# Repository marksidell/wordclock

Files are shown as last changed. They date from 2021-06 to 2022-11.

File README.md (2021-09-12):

# Word Clock

*View a 
<a href="https://www.youtube.com/watch?v=zEZTya65sJE" target="_blank">
video tour</a> of the word clock at YouTube.*

*Read all about the project on the
<a href="https://github.com/marksidell/wordclock/wiki" target="_blank">
wiki</a>.*

<a href="https://docs.google.com/spreadsheets/d/e/2PACX-1vQStdv3OZqONGQ3K7h9tHB2eYP5Ft4sCtjWJ84ZjRLP-8blSC_7sYkqp4zAAOey4n2pG4VfOC5HdfLr/pubhtml" target="_blank">
Bill of Materials</a>

## Repo Contents

### Directories

See the `README` file in each directory for more information.

| Directory | Description |
|---|---|
| <a href="https://github.com/marksidell/wordclock/tree/main/carbide3d" target="_blank">carbide3d</a> | Carbide Create designs for various clock components. |
| <a href="https://github.com/marksidell/wordclock/tree/main/code" target="_blank">code</a> | The code that needs to be copied to the Pi. |
| <a href="https://github.com/marksidell/wordclock/tree/main/code" target="_blank">docs</a> | The manual and other printed material. |
| <a href="https://github.com/marksidell/wordclock/tree/main/face" target="_blank">face</a> | Adobe Illustrator face designs for the clocks I've built. |
| <a href="https://github.com/marksidell/wordclock/tree/main/pcbs" target="_blank">pcbs</a> | KiCad printed circuit board designs. |

### Files

| File | Description |
|---|---|
| <a href="https://github.com/marksidell/wordclock/blob/main/aws-s3-policy-example.json" target="_blank">aws-s3-policy-example.json</a> | An example AWS IAM policy file for granting the word clock S3 permissions. |
| <a href="https://github.com/marksidell/wordclock/blob/main/manual.docx" target="_blank">manual.docx</a> | The user manual. |
| <a href="https://github.com/marksidell/wordclock/blob/main/pi-pinouts.md" target="_blank">pi-pinouts.md</a> | What passes for a schematic. |

## How It Works

### The Clock Program

The clock program, `wc`, runs as a systemd service. It must run as root to be able to
access the I2C hardware. The program uses the Python `asyncio` framework
for orchestrating real-time processes. You can also run the program from the command line,
with options to display verbose debugging messages.

### Calibrating the Compass

Each clock's magnetometer must be calibrated. The result of the calibration is stored
as a JSON file, `/var/wordclock/compass.json`. The word clock program reads the file
on startup. To perform a calibration, start the `calibrate` program and then slowly
rotate the magnetometer through all possible orientations.

### Phoning Home

The clock can be configured to phone home periodically, to upload systemd logs for
the clock service, and to download and install new software. The clock phones home
simply by reading and writing an AWS S3 bucket.

The clock uploads a log file daily, and saves it as `logs/<username>/log-<timestamp>.txt`,
where `<username>` is the IAM user name you'll create, as described below.

The clock checks for updates hourly. See the documentation in `wordclock/get_update.py`
for more information.

Here's what you'll need to do to make the phone-home feature work:

1. Create an S3 bucket.
2. Create an IAM User for your clock and grant it permission to access the bucket.
The file `aws-s3-policy-example.json` is an example IAM policy.
3. Create AWS API credentials for the user. Download the credential strings and store
them on the Pi, in the `[default]` section of file `/root/.aws/credentials`.

### Test Programs

The Python package includes several test programs:

| Program | Description
|---|---|
| tneo | Send test patterns to the neopixels. |
| tsense | Test and report values for the sensors: magnetometer, accelerometer, and light sensor. |
| calibrate | Calibrate the magnetometer. |

## Setting up the Pi

Notes to myself:

- Add my own ssh public key to `/home/pi/.ssh/authorized_keys`.

- Allow ssh agent forwarding when root by creating a sudoers file.
  This will allow me to use ssh to access github.

  ```
  visudo -f /etc/sudoers.d/ssh_agent_forwarding
  ```

  In VI add this line and save the file:

  ```
  Defaults env_keep += "SSH_AUTH_SOCK"
  ```

- Add this line to `/root/.ssh.config` so that I can ssh to other servers when root:

  ```
  User <my-username>
  ```

- Add wordclock-<xx> AWS credentials to `/root/.aws/credentials`:

  ```
  [default]
  aws_access_key_id = <key>
  aws_secret_access_key = <secret>
  ```

## Installation

1. Using `raspi-config`, enable `i2c`.

2. Get the contents of this repo onto the Pi.

   ```
   cd /home/pi
   git clone git@github.com:marksidell/wordclock.git
   ```

3. Create a custom `config-<xx>.py` file for your particular clock. The config files are stored
in the `config` directory.

4. Do one-time setup. This assumes you've modified the authorized_keys file to
permit login with your own key pair.

   ```bash
   cd <repo>/code
   sudo make config_sshd
   sudo make setup
   ```

5. Install everything:

   ```bash
   cd <repo>/code
   sudo make all [CONFIG=<config-file-base-name>] [S3_BUCKET=<s3-bucket-name>]
   ```

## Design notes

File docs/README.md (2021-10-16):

## Printed Material

### Files

| File | Description |
|---|---|
| steps.md | How to build the clock. |
| manual.docx | The user manual. |
| CartonLabels.* | Design and PDF files for the carton lables. |
| ManualLabels.* | Design and PDF files for the manual envelope label. |

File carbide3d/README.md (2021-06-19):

## The Carbide 3D Designs

This directory contains all of the word clock Carbide 3D milling
designs (`*.c2d`) and GCode generated from the designs (`*.nc` files).

Except as noted:

- There is a .c2d and .nc file for each design.
- The origin for all designs is the lower-left corner of the piece.

| File | Description |
|---|---|
| `BackPanel`| The MDF back panel. |
| `BandBottom` | The bottom acrylic band. The design assumes the band is placed in a jig for milling, with the jig origin 24 mm to the left of and below the band lower left corner. The offset is the height of the band, allowing another piece of pre-cut band acrylic to be used to construct the jig. |
| `Bracket.c2d` | Both the top and bottom brackets in one design. The design is for half of the bracket, and assumes the bracket is milled in two operations, one for each side. |
| `BrackTop.nc` | The gcode for the top bracket. (The top bracket is symmetric.) |
| `BrackBottomLeft.nc` | The gcode for the left side of the bottom bracket. |
| `BrackTopRight.nc` | The gcode for the right side of the bottom bracket. |
| `CenterJig` | The center jig is used to position the brackets. This design is for the notch on the bottom of the jig to accomodate the power cord that loops through the bottom bracket. |
| `CornerJig` | The jig for milling the rounded corners on the back panel. |
| `CornerJigPreMerge.c2d` | The corner jig before the elements that form the curve have been joined. Handy if you want to tweak the design. |
| `LightSensorWell` | The well cut into the clock face for the light sensor. |

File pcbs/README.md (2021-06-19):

## The Printed Circuit Board Designs

This directory contains the KiCad PCB designs, each in its own subdirectory.

| File | Description |
|---|---|
| `backlight` | The small PCB used to connect power to the backlight neopixel strip. |
| `bottom` | The "main" PCB that is attached to the bottom of the back panel. It connects power to and routes data between the face neopixels. |
| `top` | The PCB that is attached to the top of the back panel. It routes data between the face neopixels. |
| `neopixels.pretty` | A library containg the footprint for the neopixel solder pads used in the PCB designs. |

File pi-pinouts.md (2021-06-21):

## Raspberry Pi Pinouts

Sorry, this file is what passes for a schematic.

### I2C connections to the sensors (via a QWIIC cable)

| Pin | Description |
|-----|---|
| 1 | 3.3V power (red) |
| 3 | SDA (blue) |
| 5 | SCL (yellow) |
| 9 | GND (black) |

### Logic level converter connections (for driving the neopixels)

| Pin | Description |
|-----|---|
| 2 | 5V HV |
| 17 | 3.3V LV |
| 12 | LV D-out (GPIO 18) |

### Mode control button

| Pin | Description |
|-----|---|
| 14 | GND |
| 16 | D-in (GPIO 23) |

### Power

| Pin | Description |
|-----|---|
| 4 | 5V |
| 6 | GND

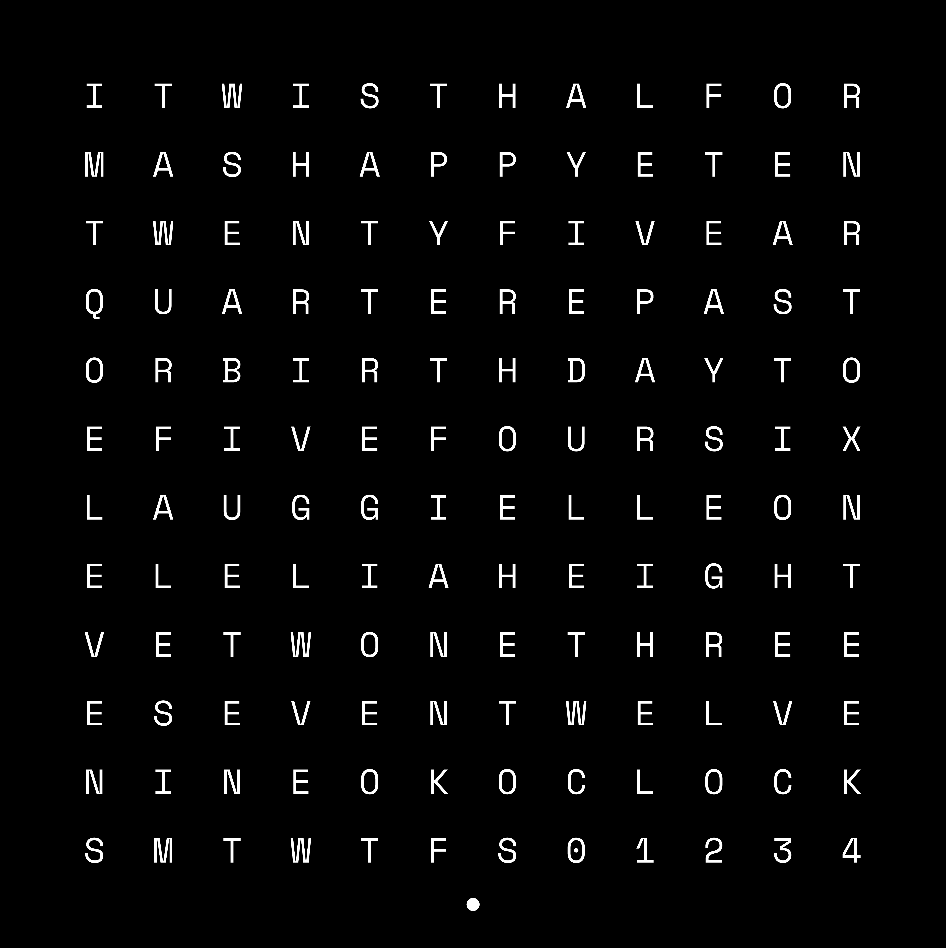
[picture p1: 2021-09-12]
face/ClockFaceAE.jpg

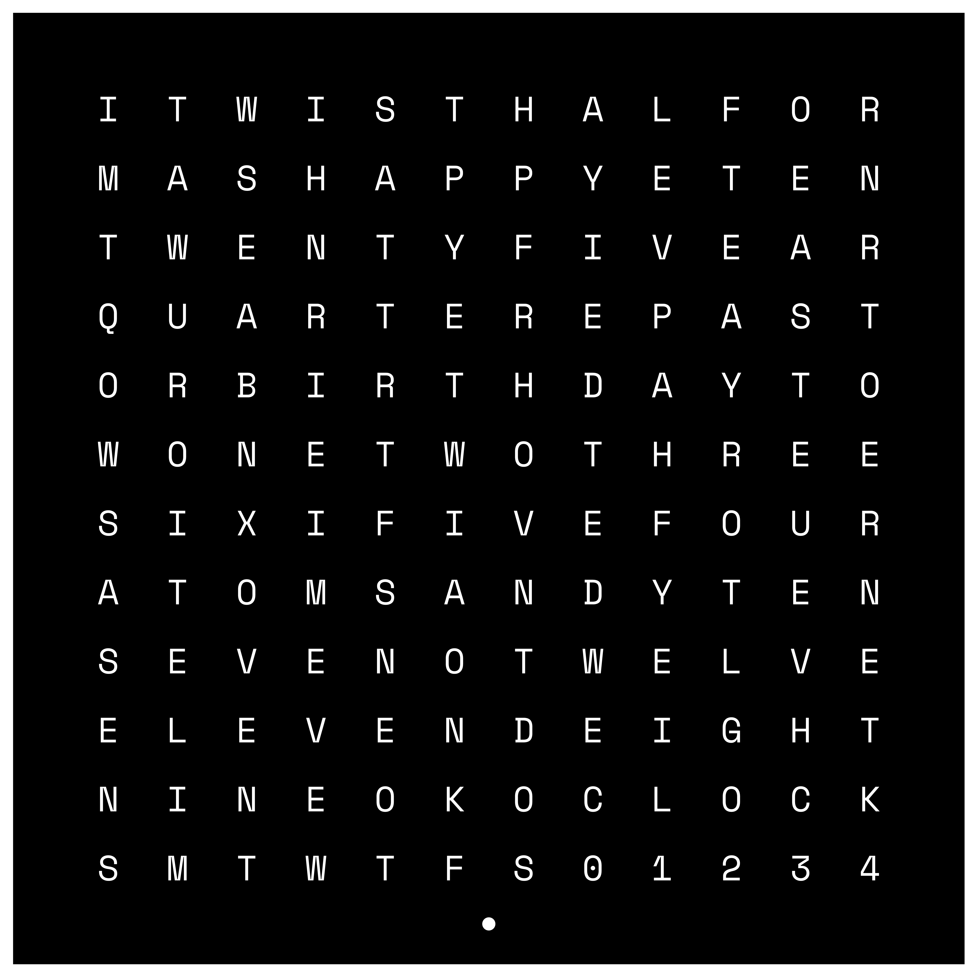
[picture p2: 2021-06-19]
face/ClockFaceTS.jpg

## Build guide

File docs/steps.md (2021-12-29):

## Setting up the SD Card

These are the minimal steps necessary to get the Pi to the point where
you can ssh to it running headless.

1. Use the Raspberry Pi Imager (on Windows) to write the image to an
SD card.

2. Mount the SD card on your Linux laptop.

4. Enable ssh:
   ```
   touch /media/sidell/boot/ssh
   cp /s/wordclock/wpa_supplicant.conf /media/sidell/boot
   ```

3. Copy the authorized_keys file:
   ```
   mkdir /media/sidell/rootfs/home/pi/.ssh
   cp /s/wordclock/code/authorized_keys /media/sidell/rootfs/home/pi/.ssh
   chown 1000:1000 -R /media/sidell/rootfs/home/pi/.ssh
   chmod 700 /media/sidell/rootfs/home/pi/.ssh
   ```

## Installing the Baseline Software

1. Unmount the SD card, put it in the pi.

2. Find the pi's IP address from dhcp and connect:
   ```
   ssh pi@<ip>
   sudo -s
   ```

3. Enable I2C and disable the GUI console.

   1. Run `raspi-config`.
   2. Select *Interface Options*.
   3. Enable I2C.
   4. Select *System Options*
   5. Select *Boot / Auto Login*
   6. Select *Console Autologin*. Don't bother rebooting now.
   4. Save and exit.

4. Create a file to enable ssh key forwarding when root, for logging
   into github:
   ```
   visudo /etc/sudoers.d/ssh_agent_forwarding
   ```

   Add this line and save the file:
   ```
   Defaults env_keep += "SSH_AUTH_SOCK"
   ```

5. Log out and back in, to enable ssh agent forwarding.

6. Install git:
   ```
   apt-get update
   apt-get -y install git
   ```

7. Clone the repo:
   ```
   git clone git@github.com:marksidell/wordclock.git
   ```

8. Do basic setup:
   ```
   cd wordclock/code
   make setup
   make config_sshd
   ```

9. Change the pi passwd.

10. Shutdown the pi. Remove the SD card and use Win32 Disk Imager to
snapshot it to the `baseline.img` in \\ruxton\share\wordclock folder.

## Installing and Configuring the Software

4. Install AWS credentials: Edit `/root/.aws/credentials` and paste the credentials
   for this particular clock.

16. Install the software, where `<xx>` is the two-letter config name for this clock.
    ```
    # This step is probably not necessary
    rm /vars/wordclock/params.json

	 cd /home/pi/wordclock/code
    make CONFIG=<xx>
    ```

## Building the Clock

1. Cut back panel. 0.5 inch MDF, 16 x 16 inches.
2. Cut 2 braces. 0.5 inch MDF, 16.5 x 2 inches.
3. Using straight edge aligned with back panel corners, find center. Then use square
to draw orthognal lines through the center. These are used to align various items
attached to the panel.

4. Mill the back panel. Place it on the MDF sacrificial base with the notch that allows
it to overhang the mill's front edge. Blue-tape the panel to the base in the corners.
Use small clamps to squeeze the front corners together while the glue sets.

5. Using the corner jig, route three back panel rounded corners. Omit the lower-right
corner, viewed from the rear of the panel.

6. Mill the brackets.

7. Glue standoffs to the brackets.

7. Mill the bottom acrylic band, using the acrylic/MDF jig.

8. Cut and tin the short power cable. 10". Attach the powerpole connector.
Solder the cable to the bottom PCB.

9. Cut the three-wire PCB jumper cable. 110 mm. Solder it to the PCB.

10. Glue the top and bottom PCBs to the back panel. Use four drops of medium-vicosity superglue,
at points where there are no PCB through-holes. Secure with four small clamps.

10. Secure the three-wire jumper cable to the bottom PCB with a dab of hot glue.

10. Cut the four-wire level converter jumper cable. 155 mm. Solder it to the level converter.

11. Cut the two-wire pushbutton jumper cable. 110 mm. Solder it to the pushbutton,
with heat shrink strain relief.

12. Solder 9x2 right-angle header to the pi. Header on TOP of pi.

13. Screw 5mm/2 standoffs to the pi, and 5mm/3 standoffs to the accelerometer, and magnetometer.
    Standoffs face UP.

13. Solder a qwiic cable to the light sensor. 90 mm (Use half of a 200 qwiic cable. Save
the other half!)

14. Screw 10mm standoffs to the acrylic electronics panel.

14. Mount the pi and sensors to the acrylic plate. Hook everything up and test.
    See [Electronics Alignment](https://photos.app.goo.gl/rrW4gMBJYJBW6XC3A).

15. Calibrate the compass:
    ```
    systemctl stop wc
    rm /var/wordclock/compass.json
    calibrate
    ```

    While `calibrate` is running, rotate the electronics assembly through all orientations.

16. Cut the face neopixel strips. Lay them out in the correct up/down pattern.
and tape them to an MDF board. Leftmost
strip is *up*.

17. Tin the neopixels. Bottom: all three, top: center only. Test for shorts.

18. Tin the top and bottom PCBs.

19. Hot glue the neopixel strips to the back panel. Use the center line for alignment.

20. Solder the strips to the PCBs. Use the hold-down jig.
Check all connections for shorts and for connectivity to the strips.

21. Hook up the pi and run `tneo --all` to test the face neopixels.

22. Solder wires to the border PCB and then solder the PCB to the neopixel strip.
The PCB sits on top of the neopixels, facing down. The wires leave the *front* of the PCB.
See [Border PCB](https://photos.app.goo.gl/wNSTMZ44nTu5heG16).

23. With the back panel clamped *face up*, glue on the border neopixels. Medium viscosity.
See [Attaching border pixels](https://photos.app.goo.gl/Qw9Kop7GaBzFSAUHA).

24. Solder the border pixel wires to the bottom strip.
See [Border pixel wiring](https://photos.app.goo.gl/Ag3d7LAccuLykpyG8).

25. Hook up the electronics and test all pixels.

17. Mount the brackets. See [Mounting brackets](https://photos.app.goo.gl/3VDmyGYpLevs3Q7WA).

    1. Angle the back panel on the multifunction table so that holes
       are close enough to clamp the bracket jig.

    2. Mark a center line on the top bracket.

    3. Mark a line 101 mm from the left edge of the bottom bracket.

    4. Draw lines along the edges of the brackets and Xs at the slot
       positions to indicate where to apply glue

    5. Nail the brackets to the back panel.

18. Drill holes for the screw eyes and mount the eyes. 1/16" drill.
Use blue tape on bit to mark 7/16" depth.

19. Attach the picture wire, with heat shrink in place.

20. Shrink the heat shrink.

21. Attach felt pads.

22. Mark hole positions on the side band drilling jig.

23. Drill holes in side bands. Place blue tape on left side of each band.

21. Glue the electronics to the back panel.

24. Attach powerpole connector to the power supply, a few inches from the
supply to minimize power loss. White stripes are red/plus.

24. Attach powerpole connectors to the white power cable.

25. Mill the light sensor well:

    1. Attach the sensor well jig to the milling machine.

    2. Tape blue tape to over the sensor hole and in the corner where the mill alignment probe sits.

    3. Clamp the face to the jig.

    4. Mill the well.

25. Using a blue tape border, paint the light sensor mask. 3" wide, 1.25" from face edge.

26. hot-glue the light sensor to the face, with spots of glue on the bottom and side edges.

27. If the sensor is proud of the face, apply electrical tape to the sides.

28. Afix 3" gaffer's tape to the back panel under the picture hook wire. Use MDF
straight edge and utility knife to cut clean edges.

29. Glue the acrylic band to the face.

    1. Clamp band alignment jigs to the table, using face and under-face for alignment.
       Position the panel so that you can clamp the brackets down while cementing the
       bands. See [Band Clamping](https://photos.app.goo.gl/cj5uuTcT4vic3L4Q9).

    2. Screw side acrylic bands to back panel brackets.

    3. Use the fourth band to align the corner.

    4. Place the back panel on the face and cement the first side band.

    5. Rotate and cement the other side.

    6. Cement the top and bottom bands.
       See [Top and Bottom Clamping](https://photos.app.goo.gl/YPZUVhCXy1rSnqiJ6).

30. Attach and connect the pushbutton.

25. Cut sides for shipping case:

    - 2 23.25"
    - 3 19"
    - 8 1" for standoffs

26. Screw the case together. Bottom try area is 2".

27. Cut cardboard sides.

28. Glue and staple back to frame.

29. Attach "OPEN THIS/OTHER SIDE" labels.

30. Place the clock face down in the case, on top of a layer of bubble wrap.

31. Tape standoffs: One at the end of each bracket, and one in each corner.

32. Cover the clock with another sheet of bubble wrap.

33. Tape the cover onto the case.

34. Tape the manual envelope and ziploc bag containing a picture hook to the case cover.

35. Ship it!

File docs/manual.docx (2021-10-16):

# Word Clock Manual

# Installation

1. Find someplace to hang the darn thing. It weighs seven pounds.
2. Plug the white cord into the PowerPole connectors on the power supply and the back of the clock. Plug in the power supply.[^1]
3. It takes about 90 seconds for the clock to boot. Pray to the gods it works.

If you refused to share your Wifi login information with the factory, you should see the 1 digit flashing pink. Jump to How to configure Wifi Step 2, below, to enter the information now.

# If it doesn’t work

If the screen is completely blank, call the factory.

If the 2 digit is flashing, it means the clock is unable to connect to WiFi. This likely means the technician configured your Wifi settings incorrectly. Continue reading.

# How to configure Wifi

To set up WiFi, you need to put the clock in hotspot mode, wherein it sets up its own Wifi hotspot. By connecting to the hotspot, you can browse to the clock’s configuration web page. Follow these steps:

1. There’s a button on the lower-right clock border. Press the button for three seconds, until the 1 digit changes color from blue to pink. Release the button. The 1 digit should start flashing pink.
2. On your favorite Internet-enabled device, connect to the wordclock Wifi hotspot, with password wordclock.
3. Browse to the wordclock.local web site. You should see a configuration page. Some devices, such as Android phones, cannot resolve the web site name. In that case, you can browse to http://10.0.0.1.
4. Enter your own Wifi SSID and password into the top two fields on the page.
5. Click the pink Save button.
6. Pray to the gods that the clock connects to your Wifi and starts displaying the time.

If it doesn’t work, try again. If it still doesn’t work, call the factory.

Once the clock is on your own Wifi, you can browse to wordclock.local from there to play with more settings.

# Display Modes

When you get bored with the clock, delight your friends with other displays. Select a mode by pressing the clock button, or by choosing a Display Mode at the top of the settings web page.

Press the button one to four times to select a mode:

Presses | Mode
1 | Toggles the display on and off. When in modes 2-4, reverts to Clock mode.
2 | Random words. Discover the hidden messages and poems!
3 | Fast Clock Demo. The clock rapidly advances the time from just before sunrise to just after sunset on the week of 7 March 2021, and repeats ad infinitum.
4 | Happy Birthday. In case you can’t wait until your actual birthday.

# Other Settings

Talk about feature creep! Manage these settings by browsing to wordclock.local.

## Be Poetic

The clock can display a random four-line poem for one minute each hour. Use this setting to choose when to display the poems. The choices are:

- Never
- At a random minute each hour (the default setting)
- At the top of each hour

## Latitude and Longitude

Tell the clock where it lives, so that it can calculate the time zone and position of the sun. The factory pre-configured the location of your home.

## Min / Max Ambient Light

The clock measures the ambient light and adjusts its brightness accordingly. Min Ambient Light is the point at which the clock sets its brightness to the lowest level; Max Ambient Light is the point at which the clock brightness is at maximum.

## Min / Max Brightness

The min and max clock brightness, on a scale of 0 to 100.

To play with the brightness settings, click the Futz With Brightness button at the bottom of the settings page. On the Futz pop-up, you can choose to view the clock at noon or midnight and use the slider to adjust the current brightness. Click the Set buttons to save your min and max choices. To make the changes permanent, exit from the pop-up and click Save.

## Sunrise Direction

Select on which side of the clock the simulated sun rises. You can choose Left Side, Right Side, or Use Compass. When using the compass, the clock figures out where the actual sunrise is and adjusts accordingly. For example, if the clock is facing south, sunrise is to the right. North is left. East or west are toss-ups.

In theory, you could carry the clock around as an actual compass, viewing the direction on the configuration web page. An accelerometer tells the clock which way us up, so it knows which two magnetometer values to use. But it’s all rather flakey. Calibrating magnetometers is hard!

[^1] Pro tip: Be sure you’re happy with the location before installing a behind-clock AC outlet.

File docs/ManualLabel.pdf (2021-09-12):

Manual Manual Manual
Manual Manual Manual
Manual Manual Manual
Manual Manual Manual
Manual Manual Manual
Manual Manual Manual
Manual Manual Manual
Manual Manual Manual
Manual Manual Manual
Manual Manual Manual

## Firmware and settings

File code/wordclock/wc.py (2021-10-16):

'''
Word Clock

CSS source:
https://www.w3schools.com/w3css/4/w3.css

jquery source:
https://ajax.googleapis.com/ajax/libs/jquery/1.10.1/jquery.min.js
'''
#pylint: disable=too-many-lines

import os
from enum import Enum
from collections import namedtuple, deque
import subprocess
import re
import datetime
import time
from argparse import ArgumentParser
import random
import math
from bisect import bisect_left
import json
import traceback
import asyncio
import pytz
import astral
from astral import sun
from aiohttp import web
from timezonefinder import TimezoneFinder
import neopixel
import RPi.GPIO as GPIO
import board
import busio
import adafruit_veml7700
from wpasupplicantconf import WpaSupplicantConf

from wordclock import __version__, config, magnetometer, configdefs

DO_CALIBRATION = False
DO_RANDOM_WORD_POEMS = True

#HOLMDELL_SSID = 'holmdell'
HOLMDELL_SSID = None

HOTSPOT_IP = '10.0.0.1'

COMPASS_JITTER_THRESHOLD = 10
AMBIENT_SMOOTHING_DEQUE_LEN = 5

LONG_PRESS_DURATION = 3

# These times are set so that the total time for one poem is 15
# seconds, allowing exactly 4 iterations in a minute.
#
N_POEM_LINES = 4       # number of lines per poem
N_POEM_LINE_WORDS = 3  # number of words in a line
POEM_WORD_PAUSE = 0.25 # pause between words, in seconds  * 2 * 4 =  2
POEM_LINE_PAUSE = 2    # pause between lines              * 3     =  6
POEM_END_PAUSE = 4     # pause at end of poem             * 1     =  4
POEM_DURATION = 15     # This causes the inter-poem time to be about 1.5 seconds

RANDOM_WORD_PAUSE = 1

SETTINGS_TITLE = '{} Clock'.format(config.CLOCK_NAME)

def scale_color(color, factor):
    ''' Return a color tuple scaled by a factor
    '''
    return tuple(int(x * factor) for x in color)


COLOR_LIGHTSKY = scale_color((135, 206, 250), 0.20)
#COLOR_NIGHTSKY = (43//8, 47//8, 119//8)
COLOR_NIGHTSKY = scale_color((25, 25, 112), 0.4)
COLOR_GROUND = scale_color((46, 139, 87), 0.7)
COLOR_MINUTE = scale_color((180, 0, 128), 0.4)
COLOR_DAY = scale_color((22, 0, 255), 1.00)
COLOR_DAY_OFF = scale_color((255, 255, 255), 0.10)
COLOR_WORD = (255, 255, 255)
COLOR_OFF = (0, 0, 0)
COLOR_BORDER_LIGHT1 = (128, 0, 255)
COLOR_BORDER_LIGHT2 = (255, 0, 128)
COLOR_SUN = (255, 255, 0)
COLOR_GOLDEN_HOUR_START = (255, 90, 34) # from IMG_3850.JPG sunrise
COLOR_RANDOM_BORDER = scale_color((180, 0, 128), 0.125)
COLOR_BUTTON_PRESS = (0, 0, 255)
COLOR_HOTSPOT_MODE = (255, 0, 64)
COLOR_LONG_BUTTON_PRESS = COLOR_HOTSPOT_MODE

DELTAS = [
    None, config.T_FIVE, config.T_TEN,
    config.T_QUARTER, config.T_TWENTY, config.T_TWENTYFIVE,
    config.T_HALF, config.T_TWENTYFIVE, config.T_TWENTY,
    config.T_QUARTER, config.T_TEN, config.T_FIVE]

HOURS = [
    config.H_TWELVE, config.H_ONE, config.H_TWO, config.H_THREE, config.H_FOUR, config.H_FIVE,
    config.H_SIX, config.H_SEVEN, config.H_EIGHT, config.H_NINE, config.H_TEN, config.H_ELEVEN,
]


RANDOM_COLORS = [
    (255, 0, 0),
    (0, 255, 0),
    (0, 0, 255),
    (255, 255, 0),
    (0, 255, 255),
    (255, 0, 255),
    (255, 255, 255),
    ]


def is_after(word0, word1):
    ''' Is word1 after word0 on the grid?
    '''
    l_word0 = len(word0.text)

    if word0.vertical:
        word0_end = word0.y + l_word0

        return (
            word1.y >= word0.y and word1.y <= word0_end and word1.x > word0.x + 1
            or word1.y > word0_end)

    word0_end = word0.x + l_word0

    if word1.vertical:
        return (
            word1.y == word0.y and word1.x > word0_end
            or word1.y == word0.y + 1 and (word1.x < word0.x - 1 or word1.x > word0_end)
            or word1.y > word0.y + 1)

    return (
        word1.y == word0.y and word1.x > word0_end
        or word1.y > word0.y)


def is_after_no_dup(word0, word1):
    ''' Is word1 after word0 on the grid, and are the words not the same?
    '''
    return word0.text != word1.text and is_after(word0, word1)


def init_poems():
    ''' Calculate poems.
        Store a list of poems that start with each word.
        Return a list of all poems, shuffled.
    '''
    # All words ordered by their position in the grid, left to right, top to bottom.
    all_words_in_grid_order = sorted(configdefs.ALL_WORDS, key=lambda x: (x.y, x.x))

    for word0 in all_words_in_grid_order:
        word0.after = [word1 for word1 in all_words_in_grid_order if is_after_no_dup(word0, word1)]

    for word0 in all_words_in_grid_order:
        word0.poems = [
            (word0, word1, word2)
            for word1 in word0.after
            for word2 in word1.after
            if is_after(word0, word2) and word2.text != 'a']

    poems = [poem for word in all_words_in_grid_order for poem in word.poems]
    random.shuffle(poems)
    return poems


# All four-word poems, in random order
ALL_POEMS = init_poems()

class State(Enum):
    ''' The operational state
    '''
    STARTING = 1
    HOTSPOT = 2
    WIFI_INIT = 3
    WIFI_ACTIVE = 4
    ERROR = 5


class DisplayMode(Enum):
    ''' What we are displaying
    '''
    CLOCK = 1
    RANDOM_WORDS = 2
    DEMO = 3
    DEMO_BIRTHDAY = 4

StatePixel = namedtuple('StatePixel', 'index color')

STATE_DISPLAY = {
    State.STARTING: StatePixel(0, (0, 0, 255)),
    State.HOTSPOT: StatePixel(1, COLOR_HOTSPOT_MODE),
    State.WIFI_INIT: StatePixel(2, (64, 0, 255)),
    State.ERROR: StatePixel(3, (255, 0, 0)),
    }

PORT_HTTP = 80

FILES_DIR = '/var/wordclock'
PARAMS_FILE = os.path.join(FILES_DIR, 'params.json')
WIFI_PARAMS_FILE = os.path.join(FILES_DIR, 'wifi.json')
BODY_FILE = os.path.join(FILES_DIR, 'website', 'body.html')

# These keys must agree with the corresponding controls on the web page.
PARAM_SSID = 'ssid'
PARAM_PASSWORD = 'password'
PARAM_LAT = 'lat'
PARAM_LON = 'lon'
PARAM_MIN_LIGHT = 'min_light'
PARAM_MIN_BRIGHTNESS = 'min_brightness'
PARAM_MAX_LIGHT = 'max_light'
PARAM_MAX_BRIGHTNESS = 'max_brightness'
PARAM_SUNRISE = 'sunrise'
PARAM_POEMS = 'poems'

WIFI_PARAMS = [PARAM_SSID, PARAM_PASSWORD]

SUNRISE_LEFT = 'left'
SUNRISE_RIGHT = 'right'
SUNRISE_COMPASS = 'compass'
DEFAULT_SUNRISE = SUNRISE_COMPASS

POEMS_OFF = 'off'
POEMS_HOURLY = 'hourly'
POEMS_RANDOMLY = 'randomly'
DEFAULT_POEMS = 'randomly'

MAX_LAT = 90
MAX_LON = 180

LatLonConfig = namedtuple('LatLonConfig', 'name param max')

LAT_CONFIG = LatLonConfig('Latitude', PARAM_LAT, MAX_LAT)
LON_CONFIG = LatLonConfig('Longitude', PARAM_LON, MAX_LON)

FUTZ_DISPLAY_NOON = 'noon'
FUTZ_DISPLAY_MIDNIGHT = 'midnight'

ABS_MIN_LIGHT = 0
ABS_MAX_LIGHT = 30000
DEFAULT_MIN_LIGHT = 500
DEFAULT_MAX_LIGHT = 2000
DEFAULT_MIN_BRIGHTNESS = 15
DEFAULT_MAX_BRIGHTNESS = 100

DisplayConfig = namedtuple('DisplayConfig', 'name param min max')

MIN_LIGHT_CONFIG = DisplayConfig('Min Ambient Light', PARAM_MIN_LIGHT, ABS_MIN_LIGHT, ABS_MAX_LIGHT)
MAX_LIGHT_CONFIG = DisplayConfig('Max Ambient Light', PARAM_MAX_LIGHT, ABS_MIN_LIGHT, ABS_MAX_LIGHT)
MIN_BRIGHTNESS_CONFIG = DisplayConfig('Min Brightness', PARAM_MIN_BRIGHTNESS, 0, 100)
MAX_BRIGHTNESS_CONFIG = DisplayConfig('Max Brightness', PARAM_MAX_BRIGHTNESS, 0, 100)
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

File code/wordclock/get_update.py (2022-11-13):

'''
Check S3 for an update. If found download and run it.

Updates are tar/gzip files. They may contain any content,
but must contain a file named "update", which we execute.
The S3 objects have names of the form:

  update/<username>/update-<yyyy><mm><dd><nn>.tgz

The <username> is the IAM username used by the clock to
authenticate to AWS, and are of the form "wordclock-<xx>".

We record which updates have been done, by creating local
directories with names of the form:

   /var/wordclock/updates/<yyyy><mm><dd><nn>

where the timestamp is the timestamp portion of the filename
downloaded from S3. We download a new update if its timestamp
is greater than the newest recorded timestamp.

The update process is:

1. List the objects in S3 and determine if there's a new update.
   Ignore object that are larger than 10MB.

2. Download the update tar object and save as a tmp file.

3. Verify that the hash of the file contents matches the S3
   object etag. Abandon any update that isn't valid.

4. Untar the file into "/var/wordclock/updates/<timestamp>/files".

5. Execute the "update" script.

6. Delete the "files" subdirectory and all of its contents,
   leaving just the timestamp directory to record that the update
   was processed.

7. Upload a log recording the result to S3.
'''

import subprocess
import os
import stat
import re
import tarfile
import traceback
import datetime
import tempfile
import shutil
from argparse import ArgumentParser
from hashlib import md5
from collections import namedtuple
import boto3
from wordclock.s3config import S3_BUCKET
from wordclock.username import get_username

UPDATES_DIR = '/var/wordclock/updates'
MAX_UPDATE_FILESIZE = 10000000
MIN_OBJ_CHUNK_SIZE = 1<<20
FILES_SUBDIR = 'files'
SCRIPT = 'update'


def parse_filename(item):
    ''' Parse an S3 object filename and return a corresponding tuple
    '''
    size = item['Size']

    if size > MAX_UPDATE_FILESIZE:
        return None

    fullname = item['Key']
    basename = fullname.split('/')[-1]
    match = re.match(r'update-(?P<timestamp>\d{10})\.tgz$', basename)

    if not match:
        return None

    return namedtuple('FilenameParts', 'fullname basename timestamp etag size')(
        fullname, basename, match.group('timestamp'), item['ETag'], size)


def download_update(s3_client, s3_filename):
    ''' Download an update file
    '''
    name = None

    try:
        with tempfile.NamedTemporaryFile(delete=False) as fil:
            name = fil.name
            shutil.copyfileobj(s3_client.get_object(Bucket=S3_BUCKET, Key=s3_filename)['Body'], fil)

    except Exception as err: #pylint: disable=broad-except
        if name and os.path.isfile(name):
            os.remove(name)

        raise RuntimeError('Unable to download file: {}'.format(err))

    return name


def verify_file(tmp_tarfile, s3_file):
    ''' Verify that the hash of the contents of the downloaded file matches the S3
        object's etag.
    '''
    etag = s3_file.etag[1:-1]     # remove enclosing quotes
    etag_split = etag.split('-')  # the format is either "<hasn>" or "<hash>-<nchunks>"

    if len(etag_split) == 1:
        with open(tmp_tarfile, 'rb') as fil:
            if etag == md5(fil.read()).hexdigest():
                return

    else:
        obj_hash = etag_split[0]
        n_chunks = int(etag_split[1])

        for chunk_size in (
                size for size in range(MIN_OBJ_CHUNK_SIZE, s3_file.size, MIN_OBJ_CHUNK_SIZE)
                if (s3_file.size + size - 1) // size == n_chunks):

            if obj_hash == chunked_hash(tmp_tarfile, chunk_size):
                return

    raise RuntimeError('File hash is not {}'.format(etag))


def chunked_hash(tmp_tarfile, chunk_size):
    ''' Calculate the etag hash of an S3 object for a given chunk size.
    '''
    concatenated_chunk_hashes = bytes()

    with open(tmp_tarfile, 'rb') as fil:
        while True:
            chunk = fil.read(chunk_size)

            if not chunk:
                break

            concatenated_chunk_hashes += md5(chunk).digest()

    return md5(concatenated_chunk_hashes).hexdigest()


def untar_file(tmp_tarfile, timestamp):
    ''' Untar the downloaded file and return the directory and script.
    '''
    try:
        target_dir = os.path.join(UPDATES_DIR, timestamp, FILES_SUBDIR)
        os.makedirs(target_dir)

        with tarfile.open(name=tmp_tarfile, mode='r:gz') as fil:
            fil.extractall(path=target_dir)

        script = os.path.join(target_dir, SCRIPT)

        if not os.path.isfile(script):
            raise RuntimeError('The tar file contains no script')

        os.chmod(script, stat.S_IRWXU)
        return namedtuple('Target', 'dir script')(target_dir, script)

    except Exception as err: #pylint: disable=broad-except
        raise RuntimeError('Unable to untar file: {}'.format(err))


def do_update(script):
    ''' Execute an update script
    '''
    try:
        return subprocess.check_output([script], stderr=subprocess.STDOUT).decode()

    except subprocess.CalledProcessError as err: #pylint: disable=broad-except
        raise RuntimeError('Script error: {}\n{}'.format(err.returncode, err.output.decode()))


def parse_args():
    ''' Parse command line args
    '''
    parser = ArgumentParser(
        prog='get-update',
        description='Download and process any update')

    parser.add_argument(
        '--debug',
        action='store_true',
        default=False,
        help='Print verbose debugging statements')

    return parser.parse_args()
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

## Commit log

2021-06-19 First public release.
    [backlight.kicad_pcb, bottom.kicad_pcb, top.kicad_pcb]
2021-06-20 fix comment; simplify conditional
    [wc.py]
2021-06-20 added inouts and BOM
2021-06-21 add links to content, and colors to QWIIC cable
2021-08-14 Increased back panel depth of cut for LED holes
2021-08-14 Handle unitialized magnetometer values
2021-09-12 actually print word and poem counts
2021-09-12 actually print word and poem counts, bug fix
    [wc.py]
2021-10-10 more poem timing fixes
    [wc.py]
